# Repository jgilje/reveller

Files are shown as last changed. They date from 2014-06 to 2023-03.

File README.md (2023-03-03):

# Reveller

Connect your SID-file (6581/8580) to a Raspberry Pi, BeagleBone Black or TinCan Tools Hammer - 
and listen to the beautiful un-emulated SID-music.

## Compiling
[sidplayer/](https://github.com/jgilje/reveller/tree/master/sidplayer) contains the core program. It emulates a simple C=64,
and redirects SID-IO to the chip. Build using CMake.

[sidplayer-web-backend/](https://github.com/jgilje/reveller/tree/master/sidplayer-web-backend) is a frontend for the core, allowing
clients to connect and control the more basic core. This project allows any websocket client to control the 'backend' of the sidplayer. This is a Go project.

[sidplayer-web-frontend/](https://github.com/jgilje/reveller/tree/master/sidplayer-web-frontend) This is a webfrontend for reveller communicating with the webscoket backend. built using js/html 

[qt-gui/](https://github.com/jgilje/reveller/tree/master/qt-gui) is a client for the frontend written in Qt. Build
using qmake.

## Schematics
Complete Eagle board layout and schematics is available for the Raspberry Pi 
 ([board](https://raw.githubusercontent.com/jgilje/reveller/master/docs/reveller-pi.brd),
  [schematics](https://raw.githubusercontent.com/jgilje/reveller/master/docs/reveller-pi.sch))
port. Schematics for the other ports are sadly undocumented for the moment, although the core has been ported
to the other platforms.

## Cases
* BeagleBone Black, available at http://www.thingiverse.com/thing:1019636

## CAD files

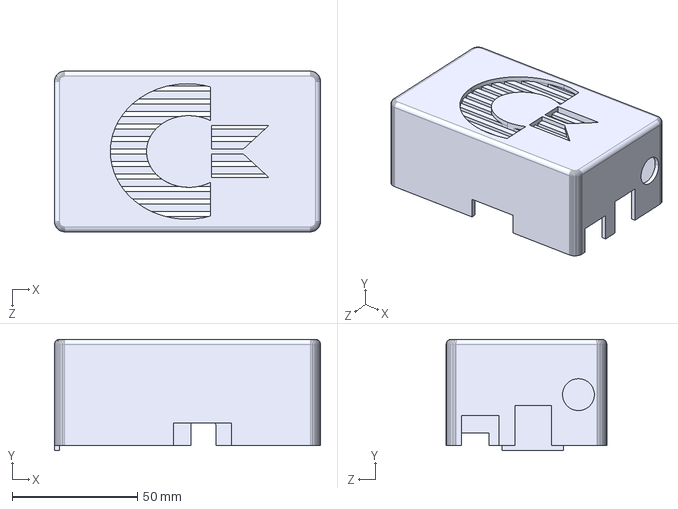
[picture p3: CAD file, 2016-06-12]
docs/boxdesign/TopCoverWithVents_Rev_A.STEP
106.0 x 44.4 x 64.0 mm

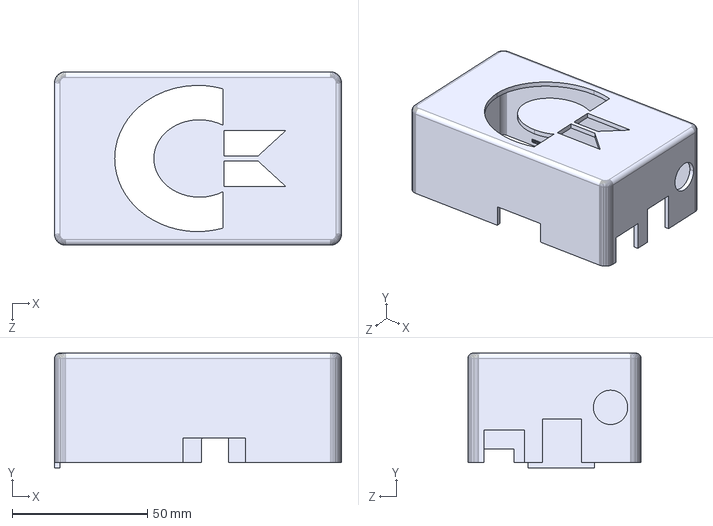
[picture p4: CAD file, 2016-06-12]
docs/boxdesign/TopCover_Rev_A.STEP
106.0 x 42.4 x 64.0 mm

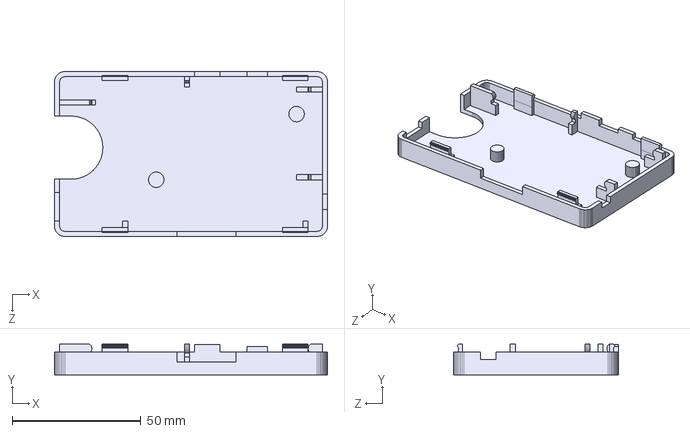
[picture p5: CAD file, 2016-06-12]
docs/boxdesign/BottomCase_Rev_A.STEP
106.0 x 12.0 x 64.0 mm

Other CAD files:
docs/boxdesign/TopCoverWithVents.SLDPRT
docs/boxdesign/TopCover.SLDPRT
docs/boxdesign/BottomCase_Rev_A.STL
docs/boxdesign/TopCoverWithVents_Rev_A.STL
docs/boxdesign/TopCover_Rev_A.STL

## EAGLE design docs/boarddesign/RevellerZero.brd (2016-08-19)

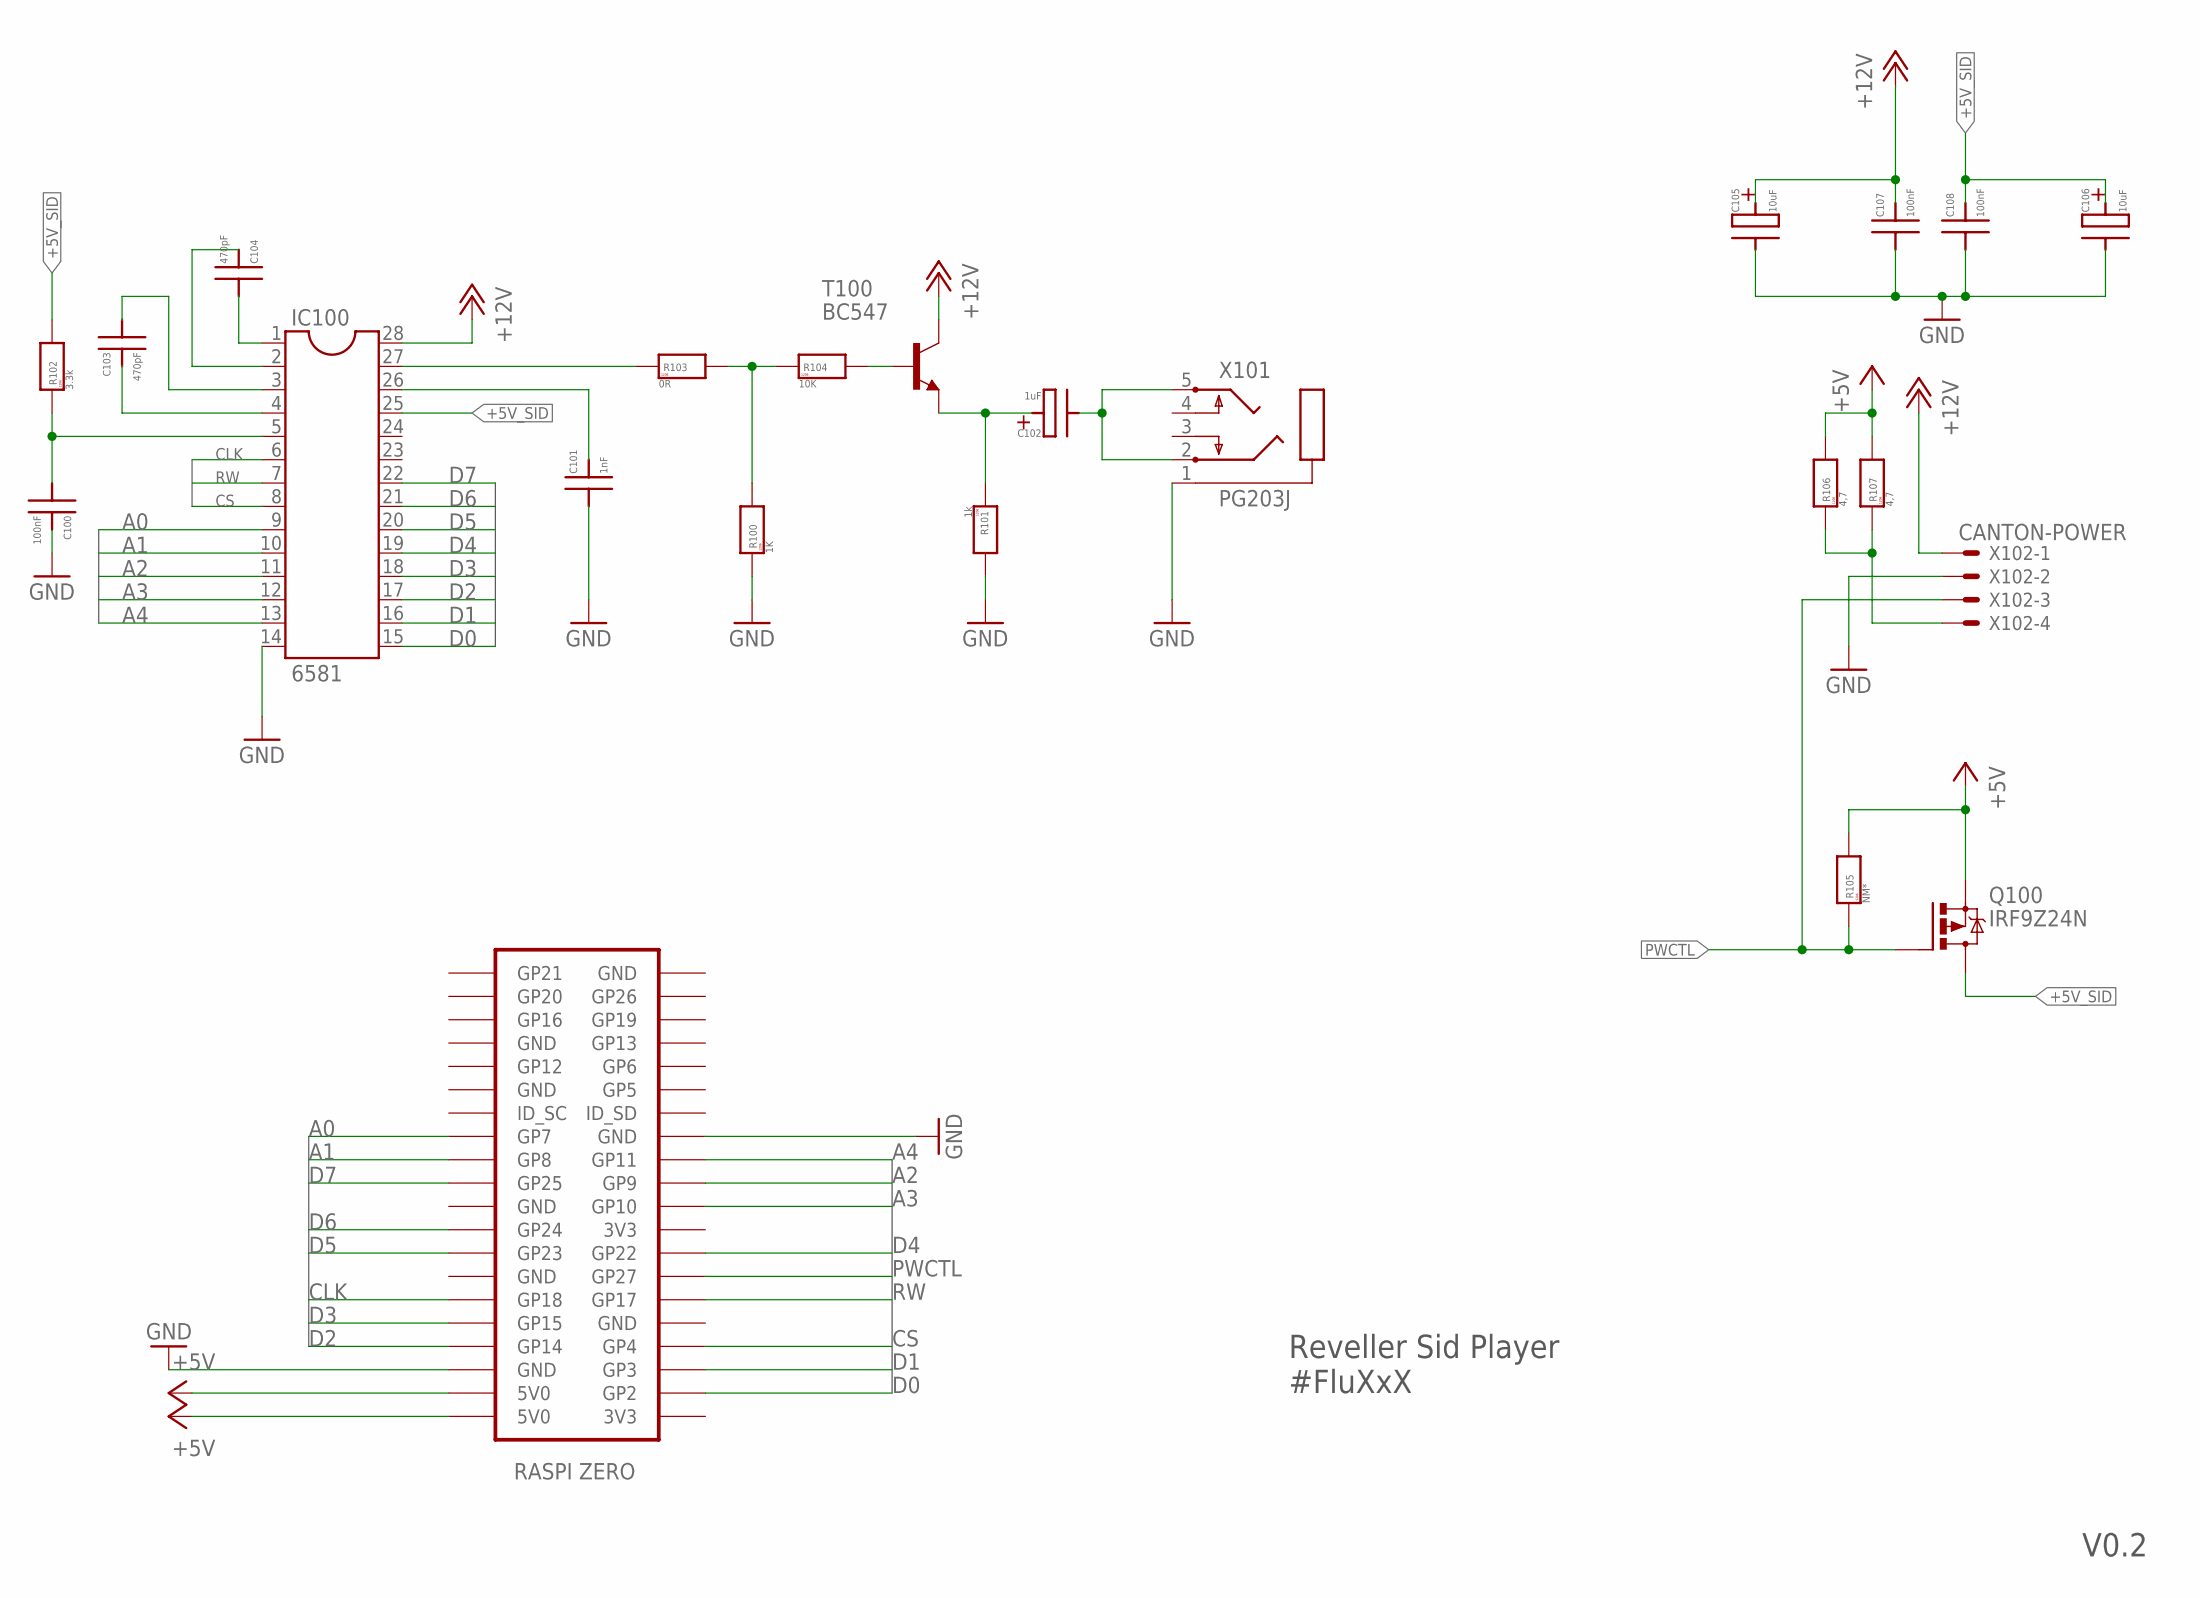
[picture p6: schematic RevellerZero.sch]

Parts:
C100, C107, C108: 100nF; SMD-IPC_C1206
C101: 1nF; SMD-IPC_C1206
C102: 1uF; PXE-H
C103, C104: 470pF; SMD-IPC_C1206
C105, C106: 10uF; SMD-IPC_CT7343
IC100: 6581; DIL28-6
Q100: IRF9Z24N; TO220BV
R100: 1K; SMD-IPC_R1206
R101: 1k; SMD-IPC_R1206
R102: 3.3k; SMD-IPC_R1206
R103: 0R; SMD-IPC_R1206
R104: 10K; SMD-IPC_R1206
R105: NM*; SMD-IPC_R1206
R106, R107: 4,7; SMD-IPC_R1206
T100: BC547; TO92
U$1: ZERO
X101: PG203J
X102: CANTON-POWER; 22-23-2041

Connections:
+5V: Q100.S, R105.2, R106.2, R107.2, U$1.2 (5V0), U$1.4 (5V0)
+5VEZ: R106.1, R107.1, X102.4
+5V_SID: C106.+, C108.+ (2), IC100.25, Q100.D, R102.2
+12V: C105.+, C107.+ (2), IC100.28, T100.3 (C), X102.1
A0: IC100.9, U$1.26 (GP7)
A1: IC100.10, U$1.24 (GP8)
A2: IC100.11, U$1.21 (GP9)
A3: IC100.12, U$1.19 (GP10)
A4: IC100.13, U$1.23 (GP11)
AUDIO_DC: C102.+, R101.1, T100.1 (E)
AUDIO_OUT: C102.-, X101.2, X101.5
AUDIO_PREAMP: R100.2, R103.2, R104.1
AUDIO_PREAMP_B: R104.2, T100.2 (B)
AUDIO_RAW: IC100.27, R103.1
CAP1A: C104.- (1), IC100.1
CAP1B: C104.+ (2), IC100.2
CAP2A: C103.- (1), IC100.3
CAP2B: C103.+ (2), IC100.4
CAPX: C101.+ (2), IC100.26
CLK: IC100.6, U$1.12 (GP18)
CS: IC100.8, U$1.7 (GP4)
D0: IC100.15, U$1.3 (GP2)
D1: IC100.16, U$1.5 (GP3)
D2: IC100.17, U$1.8 (GP14)
D3: IC100.18, U$1.10 (GP15)
D4: IC100.19, U$1.15 (GP22)
D5: IC100.20, U$1.16 (GP23)
D6: IC100.21, U$1.18 (GP24)
D7: IC100.22, U$1.22 (GP25)
GND: C100.+ (2), C101.- (1), C105.-, C106.-, C107.- (1), C108.- (1), IC100.14, R100.1, R101.2, U$1.6 (GND), U$1.25 (GND), X101.1, X102.2
PWCTL: Q100.G, R105.1, U$1.13 (GP27), X102.3
RESET: C100.- (1), IC100.5, R102.1
RW: IC100.7, U$1.11 (GP17)

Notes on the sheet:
Reveller Sid Player #FluXxX
V0.2

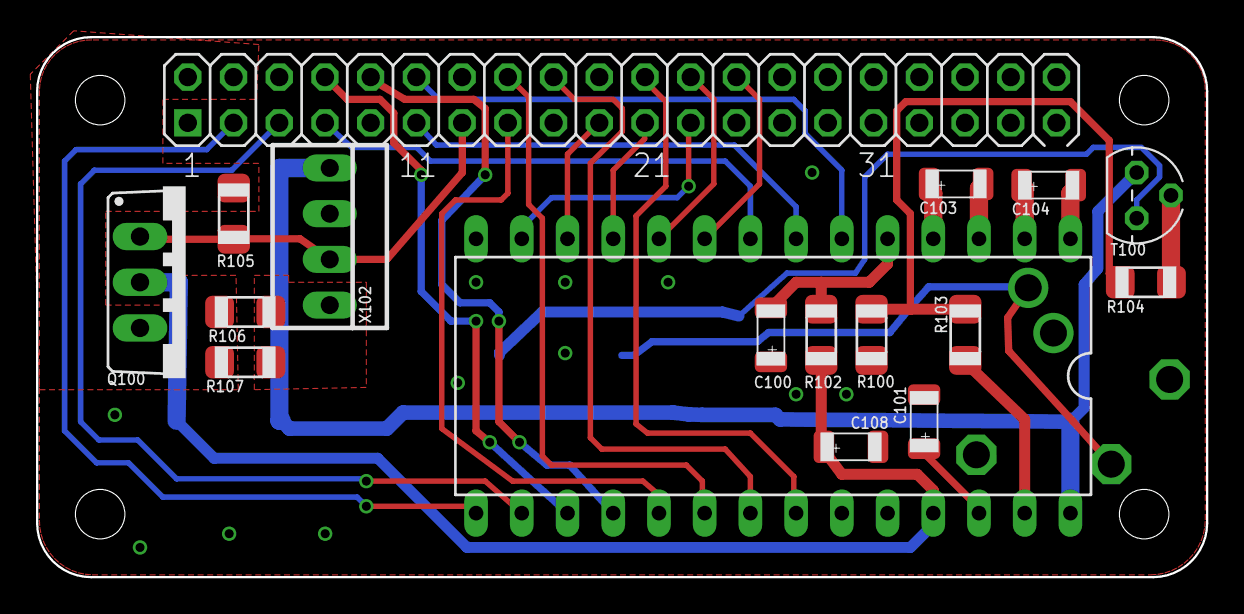
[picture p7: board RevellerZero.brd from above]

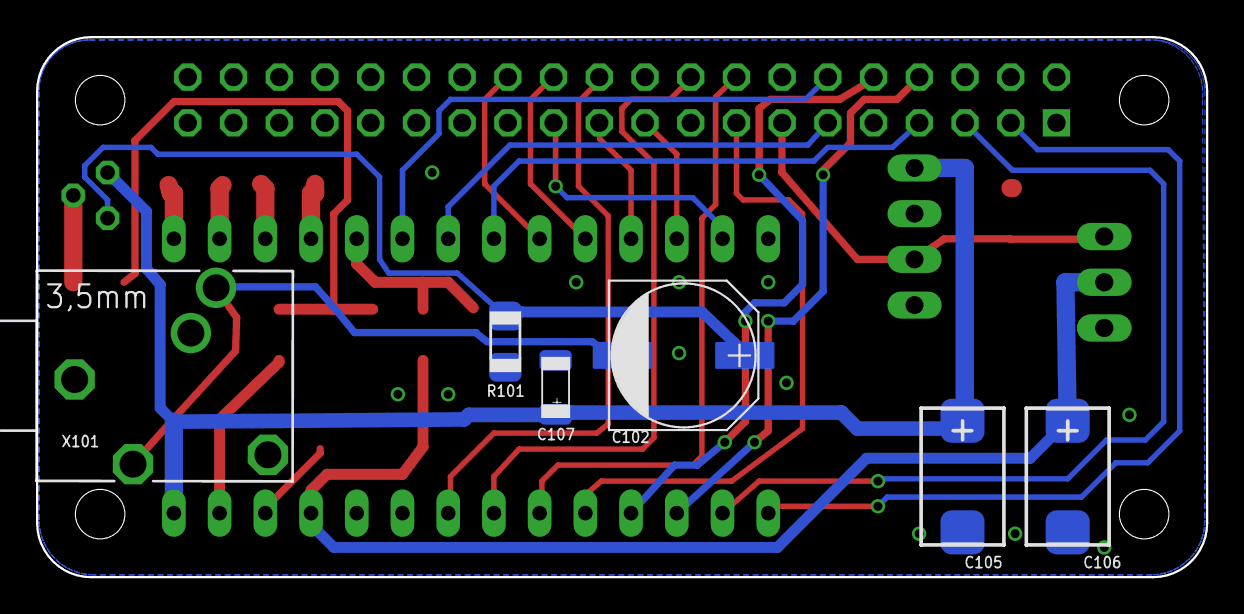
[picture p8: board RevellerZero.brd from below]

Board: 2 copper layers, 65.0 x 30.0 mm, 23 parts (6 on the bottom side), 33 nets.

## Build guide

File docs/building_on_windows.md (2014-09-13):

The sidplayer subproject builds the dummy binary with both MinGW and MSVC compiler tools.

Make sure http://www.cmake.org/ is installed and availble in your path.

Open a shell, and CD into your build folder. Run the appropriate command
for your toolset.

```Batchfile
cmake -G "Visual Studio 12" ..\..\..\sidplayer
msbuild sidplayer-dummy.vcxproj
```

```Batchfile
cmake -G "MinGW Makefiles" ..\..\..\sidplayer
mingw32-make sidplayer-dummy
```

MinGW can easily be obtained via the online installer at http://qt-project.org/downloads.

Visual Studio Express 2013 for Windows Desktop at http://www.visualstudio.com/en-us/products/visual-studio-express-vs.aspx contains the required toolset for MSVC.

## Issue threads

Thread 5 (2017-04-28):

Stop and "Power Off" button QT-GUI

tmolberg, 2017-04-28:
Great to be able to pause or stop the music inside QT application.

Power Off function would be nice so that you can still have the webserver running without the problem if the SID chip overheating if your not listening to music.

tmolberg, 2022-10-03:
No longer needed due to web interface. closing

jgilje, 2023-09-02:
not needed anymore. good work @tmolberg

Closed 2023-09-02.

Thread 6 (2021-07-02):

When SID chip is powered off 5v & 12v rail should be turned off

tmolbergen, 2021-07-02:
Review how to cut 5v and 12v from sid chip when reveller is exited.

jgilje, 2021-07-02:
nais! you know what to do :)

tmolberg, 2022-10-03:
After reviewing boarddesign it looks like 5v and 12v is cut. Closing this for now...

jgilje, 2022-10-04:
good news (tm). 5V is cut

Closed 2022-10-04.

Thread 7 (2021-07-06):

SIDChip does not get powered off when using kernel driver

tmolbergen, 2021-07-06:

tmolberg, 2022-10-03:
fixed with 5258cb82d0ff468c513fd85e0e921d62b9115e77

Closed 2022-10-03.

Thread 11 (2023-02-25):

systemd does not load kernel module for reveller

tmolberg, 2023-02-25:
When systemd is used to launch reveller on boot the kernel driver does not get loaded.

Figure out how to load kernel driver dependencies when reveller is set to start

tmolberg, 2024-08-29:
solved with commits bc65fd8bd7096a922209b9d8947569593142da3d 6c4f3b913e9a2edcefd0b13185a4189113f46840

Closed 2024-08-29.

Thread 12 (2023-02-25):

flag to indicate if reveller should start in off or on state

tmolberg, 2023-02-25:
whenever reveller is started the 12v rail is automaticly powered on.

with the webui and automatic power on via systemd this might not be needed or wanted.

Closed 2023-09-02.

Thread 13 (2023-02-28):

add support for ws/wss switcher for frontend based on http/https

tmolberg, 2023-02-28:
when ssl termination is done on a reverse-proxy, the javascript should detect whether or not to use ws/wss and let the reverse-proxy do the ws ssl termination

tmolberg, 2023-03-03:
fixed in db9a3f292f778a335269664aee44f8da18675286

Closed 2023-03-03.

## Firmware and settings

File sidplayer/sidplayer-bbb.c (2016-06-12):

#include <stdint.h>
#include <stdio.h>
#include <stdlib.h>
#include <string.h>
#include <termios.h>
#include <unistd.h>
#include <fcntl.h>
#include <sys/mman.h>
#include <sched.h>

#include "6510.h"
#include "am335x.h"
#include "console-interface.h"

FILE *inputSidFile = NULL, *sid_kernel_timer = NULL;
int fd_mem = -1;

void* get_addr(uint32_t addr) {
	void* m = mmap(0, MAP_SIZE, PROT_READ | PROT_WRITE, MAP_SHARED, fd_mem, addr & ~MAP_MASK);
	if(m == (void *) -1) {
		printf("Failed to map addr.: %x\n", addr);
		exit(-1);
	}
	
	return m;
}

void release_addr(void* addr) {
	int r = munmap(addr, MAP_SIZE);
	if (r != 0) {
		printf("Failed to unmap addr.: %p\n", addr);
		exit(-1);
	}
}

/*
 * enable the required subsystems
 * before they are enabled, register accesses causes memory errors
 * (ex. "Bus Error", "Unhandled fault: external abort on non-linefetch (0x1018) at 0xXXXXXXXX")
 */
void initPeripherals(void) {
	am335x_registers.clock_manager = get_addr(CM_PER);
	
	uint32_t gpio_1_status = *(am335x_registers.clock_manager + CM_PER_GPIO1_CLKCTRL);
	uint32_t gpio_2_status = *(am335x_registers.clock_manager + CM_PER_GPIO2_CLKCTRL);
	uint32_t pwm_1_status = *(am335x_registers.clock_manager + CM_PER_EPWMSS1_CLKCTRL);
	
	if (gpio_1_status & CLKCTRL_STATUS_DISABLED) {
		*(am335x_registers.clock_manager + CM_PER_GPIO1_CLKCTRL) = CLKCTRL_MODE_ENABLE;
	}
	if (gpio_2_status & CLKCTRL_STATUS_DISABLED) {
		*(am335x_registers.clock_manager + CM_PER_GPIO2_CLKCTRL) = CLKCTRL_MODE_ENABLE;
	}
	if (pwm_1_status & CLKCTRL_STATUS_DISABLED) {
		*(am335x_registers.clock_manager + CM_PER_EPWMSS1_CLKCTRL) = CLKCTRL_MODE_ENABLE;
	}
}

void initGPIO(void) {
	uint32_t oe;
	am335x_registers.control_module = get_addr(CONTROL_MODULE);

	// TODO verify we need to update the CONTROL_MODULE
	/*
	printf("%x %x %x\n", CONTROL_MODULE, am335x_registers.control_module, am335x_registers.control_module + (0x870/4));
	uint32_t z = *(am335x_registers.control_module + (0x878 / 4));
	printf("current contents of 0x870: %x\n", z);
	*/
	am335x_registers.gpio_0 = get_addr(GPIO_0);
	am335x_registers.gpio_0_clear = am335x_registers.gpio_0 + (GPIO_CLEAR_OFFSET);
	am335x_registers.gpio_0_set = am335x_registers.gpio_0 + (GPIO_SET_OFFSET);
	am335x_registers.gpio_0_oe = am335x_registers.gpio_0 + (GPIO_OE_OFFSET);
	oe = *am335x_registers.gpio_0_oe;
	oe &= 0x3FFFF07F;	// output on pin 31, 30, 11 <-> 7
	*am335x_registers.gpio_0_oe = oe;

	am335x_registers.gpio_1 = get_addr(GPIO_1);
	am335x_registers.gpio_1_clear = am335x_registers.gpio_1 + (GPIO_CLEAR_OFFSET);
	am335x_registers.gpio_1_set = am335x_registers.gpio_1 + (GPIO_SET_OFFSET);
	am335x_registers.gpio_1_oe = am335x_registers.gpio_1 + (GPIO_OE_OFFSET);
	oe = *am335x_registers.gpio_1_oe;
	oe &= 0xEFFF7FFF;	// output on pin 16 and 28
	*am335x_registers.gpio_1_oe = oe;
	
	am335x_registers.gpio_2 = get_addr(GPIO_2);
	am335x_registers.gpio_2_clear = am335x_registers.gpio_2 + (GPIO_CLEAR_OFFSET);
	am335x_registers.gpio_2_set = am335x_registers.gpio_2 + (GPIO_SET_OFFSET);
	am335x_registers.gpio_2_oe = am335x_registers.gpio_2 + (GPIO_OE_OFFSET);
	oe = *am335x_registers.gpio_2_oe;
	oe &= 0xFFFFC03F;	// output on pin 13 <-> 6
	*am335x_registers.gpio_2_oe = oe;

	// Clear POWER
	*am335x_registers.gpio_1_clear = (1 << 16);
	
	// Set RESET
	*am335x_registers.gpio_1_set = (1 << 28);
}

#define PWM_TBCTL (0x0 / 2)
#define PWM_TBSTS (0x2 / 2)
#define PWM_TBCNT (0x8 / 2)
#define PWM_TBPRD (0xA / 2)
#define PWM_CMPCTL (0xE / 2)
#define PWM_CMPA  (0x12 / 2)
#define PWM_AQCTLA (0x16 / 2)
void initPWM(void) {
	volatile uint32_t* pwm = get_addr(PWM_1);
	volatile uint16_t* tbctl_reg = (uint16_t*)(pwm + EPWM_OFFSET) + PWM_TBCTL;
	volatile uint16_t* tbsts_reg = (uint16_t*)(pwm + EPWM_OFFSET) + PWM_TBSTS;
	am335x_registers.pwm_tbcnt = (uint16_t*)(pwm + EPWM_OFFSET) + PWM_TBCNT;
	volatile uint16_t* tbprd_reg = (uint16_t*)(pwm + EPWM_OFFSET) + PWM_TBPRD;
	volatile uint16_t* cmpctl_reg = (uint16_t*)(pwm + EPWM_OFFSET) + PWM_CMPCTL;
	volatile uint16_t*   cmpa_reg = (uint16_t*)(pwm + EPWM_OFFSET) + PWM_CMPA;
	volatile uint16_t* aqctla_reg = (uint16_t*)(pwm + EPWM_OFFSET) + PWM_AQCTLA;
	
	uint32_t tbctl_tbsts = *(pwm + EPWM_OFFSET + PWM_TBCTL);
	uint16_t tbctl = *tbctl_reg;
	uint16_t tbsts = *tbsts_reg;
	uint16_t tbcnt = *am335x_registers.pwm_tbcnt;
	uint16_t tbprd = *tbprd_reg;
	uint16_t cmpctl = *cmpctl_reg;
	uint16_t   cmpa = *cmpa_reg;
	printf("%p %p\n", tbctl_reg, tbsts_reg);
	printf("Combined: %x, CTL: %x, STS: %x\n", tbctl_tbsts, tbctl, tbsts);
	
	printf("%x %x\n", tbcnt, tbprd);
	printf("%x %x\n", cmpctl, cmpa);
	
	/*
	TBCTL[CNTLDE]
	TBCTL[SWFSYNC]
	*/
	
	/*
	Counter-compare (CC)
		• Specify the PWM duty cycle for output EPWMxA and/or output EPWMxB
		• Specify the time at which switching events occur on the EPWMxA or EPWMxB output
	*/
	
	/* time based 1MHz PWM */
	/* Set HSPCLKDIV: /1, CTRMODE: Up-count */
	tbctl &= 0xfc7c;
	//printf("mod. tbctl: %x\n", tbctl);
	*tbctl_reg = tbctl;
	*am335x_registers.pwm_tbcnt = 500;
	/* Set Period */
	*tbprd_reg = 50;
	/* Action when the counter equals the period: Toggle EPWMxA output */
	// printf("aqctla_reg: %x\n", *aqctla_reg);
	*aqctla_reg = 0x3;
	
	/* Set HSPCLKDIV: /1 */
	//tbctl &= 0xfc7f;
	//*tbctl_reg = tbctl;
	//*tbprd_reg = 101;
	//*cmpa_reg = 51;
	//*aqctla_reg = (0x2 << 4) | 0x1;
	
	// while (*tbcnt_reg < 25);
	// while (*tbcnt_reg < 25);
}

void printWelcome(void) {
	printf("SID Companiet - 6510 Emulator\n");
	printf("\tLinux Hosted for Beaglebone Black\n");
    c64_printOpcodeStats();
}

void set_realtime(void) {
	struct sched_param param;
	param.sched_priority = 20;
	if (sched_setscheduler(0, SCHED_FIFO, &param) != 0) {
		printf("Failed to get RealTime priority");
	}
}

// SangSpilling foregår ved å sette registerene A (X, Y) før en kaller opp interpreteren
int main(int argc, char **argv) {
	if((fd_mem = open("/dev/mem", O_RDWR | O_SYNC)) == -1) {
		printf("Could not get /dev/mem\n");
		return -1;
	}
	
	set_realtime();
	printWelcome();
	initPeripherals();
	initGPIO();
	initPWM();

	// sjekk opp argv[1]
	if (argv[1]) {
		inputSidFile = fopen(argv[1], "rb");
		if (inputSidFile == 0) {
			printf("ERROR: File %s not found\n", argv[1]);
			exit(1);
		}
		fseek(inputSidFile, 0, SEEK_END);
		printf("Inputfile is %ld bytes\n", ftell(inputSidFile));
		
        c64_setSubSong(0);
		printf("Loaded song %d of %d subsongs\n", sh.startSong, sh.songs);
	}

	console_interface();
	return 0;
}

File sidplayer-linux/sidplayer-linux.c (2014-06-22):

#include <stdint.h>
#include <stdio.h>
#include <stdlib.h>
#include <string.h>
#include <termios.h>
#include <unistd.h>
#include <fcntl.h>
#include <time.h>
#include <sys/mman.h>

#include "6510.h"
#include "sidheader.h"

#include "sc2410.h"
#include "lcd.h"

FILE *inputSidFile, *sid_kernel_timer;
int fd_mem = -1;

s3c2410_registers_t s3c2410_registers;

#define USLEEP_CLK 0
#define USLEEP_NANOSLEEP 1
#define USLEEP_CLOCK_NANOSLEEP 2
#define USLEEP_SID_KERNEL_DRIVER 3
int usleep_function = USLEEP_SID_KERNEL_DRIVER;

void* get_addr(uint32_t addr) {
	void* m = mmap(0, MAP_SIZE, PROT_READ | PROT_WRITE, MAP_SHARED, fd_mem, addr & ~MAP_MASK);
	if(m == (void *) -1) {
		printf("Failed to map addr.: %x\n", addr);
		exit(-1);
	}
	
	return m;
}

void release_addr(void* addr) {
	int r = munmap(addr, MAP_SIZE);
	if (r != 0) {
		printf("Failed to unmap addr.: %x\n", addr);
		exit(-1);
	}
}

void initGPIO(void) {
	s3c2410_registers.v_gpio_base = get_addr(GPACON);
	s3c2410_registers.v_gpio_b_conf = s3c2410_registers.v_gpio_base + (GPBCON & MAP_MASK);
	s3c2410_registers.v_gpio_c_conf = s3c2410_registers.v_gpio_base + (GPCCON & MAP_MASK);
	s3c2410_registers.v_gpio_c_data = s3c2410_registers.v_gpio_base + (GPCDAT & MAP_MASK);
	s3c2410_registers.v_gpio_e_conf = s3c2410_registers.v_gpio_base + (GPECON & MAP_MASK);
	s3c2410_registers.v_gpio_e_data = s3c2410_registers.v_gpio_base + (GPEDAT & MAP_MASK);
	s3c2410_registers.v_gpio_g_conf = s3c2410_registers.v_gpio_base + (GPGCON & MAP_MASK);
	s3c2410_registers.v_gpio_g_data = s3c2410_registers.v_gpio_base + (GPGDAT & MAP_MASK);
	
	// gpio_c: pin 0,1 as input (read clk), rest as outputs
	// gpio_c_(8-15) is the data bus
	*(REG s3c2410_registers.v_gpio_c_conf) = 0x55555550;
	*(REG s3c2410_registers.v_gpio_c_data) = CS_ALL;		// all CS pins to high
	
	// gpio e 11-15 as outputs (problems reading from 14-15, so they are unused)
	// using gpio_e_(11,12,13) for SID addressing
	*(REG s3c2410_registers.v_gpio_e_conf) = 0x55400000;
	
	// all gpio g as outputs
	// using gpio_g_(2,3) for SID addressing
	*(REG s3c2410_registers.v_gpio_g_conf) = 0x55555555;
}

// 1.023MHz (PAL)
// 0.985MHz (NTSC)
void initPWM(void) {
	s3c2410_registers.t_base = get_addr(TCFG0);
	s3c2410_registers.v_tcfg1  = s3c2410_registers.t_base +  (TCFG1 & MAP_MASK);
	s3c2410_registers.v_tcon   = s3c2410_registers.t_base +   (TCON & MAP_MASK);
	s3c2410_registers.v_tcntb0 = s3c2410_registers.t_base + (TCNTB0 & MAP_MASK);
	s3c2410_registers.v_tcmpb0 = s3c2410_registers.t_base + (TCMPB0 & MAP_MASK);
	s3c2410_registers.v_tcntb1 = s3c2410_registers.t_base + (TCNTB1 & MAP_MASK);
	
	// tclk0 out
	uint32_t res = *(REG s3c2410_registers.v_gpio_b_conf);
	uint32_t w = res;
	w |= 0x2;
	*(REG s3c2410_registers.v_gpio_b_conf) = w;
	
	// timer1 prescaler=>1/16, timer1 will now run at 3.125MHz
	w = *(REG s3c2410_registers.v_tcfg1);
	w &= ~0xf0;
	w |= 0x30;
	*(REG s3c2410_registers.v_tcfg1) = w;
	
	// counter and compare to 24 (0x18) & 12 (0xC)
	// from listening 26-13 SOUNDS correct
	*(REG s3c2410_registers.v_tcntb0) = 25;
	*(REG s3c2410_registers.v_tcmpb0) = 13;
	
	// enable timer0
	res = *(REG s3c2410_registers.v_tcon);
	w = res & 0xffffff00;
	*(REG s3c2410_registers.v_tcon) = w | 0xa;
	usleep(1000);
	*(REG s3c2410_registers.v_tcon) = w | 0x9;
}

void setPWM(uint8_t counter, uint8_t compare) {
	void* tcfg0 = get_addr(TCFG0);
	
	void* v_tcntb0 = tcfg0 + (TCNTB0 & MAP_MASK);
	void* v_tcmpb0 = tcfg0 + (TCMPB0 & MAP_MASK);

	*(REG v_tcntb0) = counter;
	*(REG v_tcmpb0) = compare;
	
	release_addr(tcfg0);
}

void printWelcome() {
	printf("SID Companiet - 6510 Emulator\n");
	printf("\tLinux Hosted. Dev 16\n");
	PrintOpcodeStats();
}

char* nextToken(char* in) {
	int i;
	for (i = 0; i < strlen(in); i++) {
		if (in[i] == ' ') {
			in[i] = 0x0;
			return(&in[i + 1]);
		}
	}
	return NULL;
}

/*
void usleep_sid_clk(uint32_t cycles) {
	void* v_gpc_data = v_gpio_base + (GPCDAT & MAP_MASK);
	int i;
	
	for (i = 0; i < cycles; i++) {
		while (*(REG v_gpc_data) & CS_CLK);			// wait for low
		while (!(*(REG v_gpc_data) & CS_CLK));		// wait for high
	}
}

void usleep_nanosleep(uint32_t cycles) {
	struct timespec time;
	
	time.tv_sec = 0;
	time.tv_nsec = cycles*1000;
	
	if (nanosleep(&time, NULL) != 0) {
		printf("clock_nanosleep() failed\n");
	}
}

void usleep_clock_nanosleep(uint32_t cycles) {
	struct timespec time;
	
	time.tv_sec = 0;
	time.tv_nsec = cycles*1000;
	
	if (clock_nanosleep(CLOCK_REALTIME, 0, &time, NULL) != 0) {
		printf("clock_nanosleep() failed\n");
	}
}

#define NS_IN_S 1000000000
void usleep_burn(uint32_t cycles) {
	struct timespec now, start;
	int d = 0;
	int cycles_ns = cycles*1000;
	
	clock_gettime(CLOCK_PROCESS_CPUTIME_ID, &start);
	
	while (d < cycles_ns) {
		d = 0;
		clock_gettime(CLOCK_PROCESS_CPUTIME_ID, &now);
		if (now.tv_sec != start.tv_sec) {
			d += NS_IN_S;
		}
		d += (now.tv_nsec - start.tv_nsec);
	}
}
*/

void print_song(void) {
	char songname[21];
	char songauthor[21];
	char songsubsong[21];
	char copyright[21];
	snprintf(songname, 21, "%s", sh.name);
	snprintf(songauthor, 21, "%s", sh.author);
	snprintf(copyright, 21, "(C) %s", sh.released);
	snprintf(songsubsong, 21, "Song %d of %d", c64_current_song+1, sh.songs);
	
	lcd_clear();
	lcd_gotoxy(0, 0);
	lcd_puts(songname);
	lcd_gotoxy(0, 1);
	lcd_puts(songauthor);
	lcd_gotoxy(0, 2);
	lcd_puts(copyright);
	lcd_gotoxy(0, 3);
	lcd_puts(songsubsong);
}

void usleep_sid_kernel_timer(int32_t usec) {
	/*
	char buf[1];
	// enable timer1
	uint32_t res = *(REG s3c2410_registers.v_tcon);
	uint32_t w = res & 0xfffff0ff;
	
	uint32_t count = (usec * 3125) / 1000;
	*(REG s3c2410_registers.v_tcntb1) = count;
	*(REG s3c2410_registers.v_tcon) = w | 0x200;	// timer1: one-shot, inverter-off, update tcntb1, stopped
	*(REG s3c2410_registers.v_tcon) = w | 0x100;	// clear update-tcntb1, start
	
	fread(buf, 1, 1, sid_kernel_timer);
	*/
	if (usec < 0) {
		return;
	}
	if (usec > 20971) {
		printf("sidplayer: usec was %d, limiting to 20950\n", usec);
		usec = 20950;
	}
	
	ioctl(fileno(sid_kernel_timer), usec);
}
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

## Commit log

2011-10-04 fixes after testing output from GPIO with a scope
    [sidplayer-linux.c]
2011-10-07 working version, still bugs on some tunes (eg. monty)
    [sidplayer-linux.c]
2011-10-08 fix loading of sids not started on zero offset
    [6510.c, sidplayer-linux.c]
2011-11-08 kernel driver for sid-timer
2011-11-08 moved wait-for-interrupt logic inside c64_play()
2011-11-14 redesigned kernel-driver around a ioctl call
    [sidplayer-linux.c]
2011-12-10 insane menu! lcd-display fixes (speed)
    [lcd.c, sidplayer-hammer-gpio-linux.c, sidplayer-linux.c]
2014-07-19 current song is now a navbar, disable gui after crash
2014-07-31 install driver in free pages as marked by SID file
2014-09-13 fetch current header
2014-09-13 initial BBB SID Cape wiring info
2014-09-13 moved hammer kernel driver to subdirectory
2014-09-13 BeagleBone Black: update pin config, because I'm to lazy to learn DTO
2014-09-22 Reveller-Pi Eagle Schematics
    [reveller-pi.sch]
2014-10-01 store processor flags in interrupt
2014-10-05 update timer cycles in interpreter loop, to support songs where init-routine loops endlessly while waiting for interrupts
2014-10-05 PSID files uses SID Driver as IRQ routine
2014-10-06 splitted init interpreter to new function which handles nested IRQs. don't reset stack pointer when triggering IRQ/NMI. use RTI in SIDDriver. fetch SIDDriver fetches IOport from playAddress
    [6510.c]
2014-10-09 clear RESET after init
    [sidplayer-bbb.c]
2014-10-09 promoted pwm_tbcnt to am335x_registers
2014-10-09 reverted to prev. 1MHz PWM until further debugging
    [sidplayer-bbb.c]
2015-01-19 enable output on POWER-pin
2015-03-23 updated schematics
    [reveller-pi.sch]
2015-03-25 updated with mini-audio jack and power control
    [reveller-pi.sch]
2015-03-25 enabled power control
2015-03-26 removed mistaken D7 connection to pin 20, switched rpi header gnd to gnd-symbol, switched capacitors to 2.5x5
    [reveller-pi.sch]
2015-04-07 Added boarddesign
    Added boarddesign and some revisions on the schmatic regarding safety
    features for the SID Chip
    [reveller-pi.brd, reveller-pi.sch]
2015-04-09 Revised boarddesign and schmatic for better powercontrol
    Cleaned up the board with, everything done by Morten Leikvoll.
    [reveller-pi.brd, reveller-pi.sch]
2015-04-10 More revisions...
    [reveller-pi.brd, reveller-pi.sch]
2015-04-13 Completed powercontrol and boarddesign
    [reveller-pi.brd, reveller-pi.sch]
2015-04-15 Changed from holemounted caps and res to SMDs
    Changed to get a better board design, Morten Leikvoll did all of this
    because he ment he would look more nice with some of the caps and res.
    on the backside og the board.
    [reveller-pi.brd, reveller-pi.sch]
2015-05-06 Changed schmatic to allow for "stereo" sound
    Used wrong pinout on jack connector, thereby giving only mono sound.
    Also added one 1000uF capacitor to allow for bad powersupplys to not
    kill the raspberrypi during startup of sidchip
    [reveller-pi.sch]
2015-05-10 enabled poweron / poweroff for raspberry pi, with compat. for both rev1 and rev2 boards
2015-05-23 now shows sidfiles and back button implemented
2016-02-03 replaced cap with resistor
    Switched out Capacitor with resistors as its better.
    [reveller-pi.brd, reveller-pi.sch]
2016-03-29 Added boardesign for PiZero
    Boarddesign for PiZero, might be subjected to revision
    [RevellerZero.brd, RevellerZero.sch]
2016-03-29 relocated boarddesigns
    [RevellerZero.brd, RevellerZero.sch, reveller-pi.brd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]
2016-03-30 Added schmatics for B+ Hat design
    Should be working with Raspberry Pi B+/2/3. Next step is to add jumper
    possibilty to add support for Odroid C1 thanks to Knut Petter Molberg
    [reveller-pi-B+HAT.brd, reveller-pi-B+HAT.sch, reveller-pi-REVB.brd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]
2016-05-13 track refactoring
2016-06-12 Added box design and revised RevellerZero design
    Raspberry Pi Rev B box design to allow for reveller HAT. Can be printed
    with or without vented design. Designed in Solidworks 2016. RevellerZero
    board design was revised due to CantonPower being placed slightly off
    board.
    [BottomCase_Rev_A.STEP, BottomCase_Rev_A.STL, RevellerZero.brd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]
2016-07-09 cleanups! no longer hangs because of buffer errors when reading from userspace, autodetect rpi1/2 at load, restart timer if 'lost', reduced input buffer to 64k
    [reveller.c]
2016-07-09 makefile for kernel driver
2016-07-23 shorted timer request, giving better sample playback rate
    [reveller.c]
2016-07-23 c64_play() adjusts from platform Hz to µs, removed old (and wrong) conversion from console-interface
    [6510.c]
2016-08-09 corrected base-adress for rpi1 pwm init
    [platform-support-rpi.c]
2016-08-16 Revision of RevellerZero boarddesign
    Moved Cantonpower closer to gpio pins and a little further away from sid
    chip as its currently hitting the chip.
    [RevellerZero.brd]
2016-08-19 Cleanup
    Added Fluxxx and RevellerZero markings
    [RevellerZero.brd, RevellerZero.sch]
2018-02-25 the devicetree node for the RPi SoC has been defined under different names. this commit adds support for the newer style names
2021-08-04 refactored kernel module, use the device-tree/of api's to fetch io adresses and irq for us. pi4 support added.
2021-08-04 handle pi4 and pi(other) differences in timer frequencies
2021-12-29 fixed up compilation on gcc10+ due to -fno-common being default
    [6510.c]
2022-09-08 enable power management - on/off
2022-09-08 power command from websocket
2022-09-09 add current power state to the sidplayer's state
2023-09-02 case-insensitive file search, closes #9
2023-09-02 added dummy implementations of reveller_platform power and shutdown
2023-09-02 start in power off. automatically turn on power when playing a song. closes #12
2023-09-02 add missing newline for power commands
2024-08-16 make the kernel driver compatible with kernel >= 6.4
2024-08-29 install module load file
    this should make systemd automaticly load reveller kernel driver
2026-05-20 fixed function prototypes
2026-05-21 go: squelched a couple of warnings
2026-05-21 switch qt build to using cmake, integrated with main build
2026-05-23 change the write cycle, removed glitches from playback
    [platform-support-rpi.c, reveller.c]
